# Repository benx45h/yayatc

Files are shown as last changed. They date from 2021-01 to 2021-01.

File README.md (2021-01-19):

# YAYATC- Yet Another YATC
### A new temperature controller, because the YATC links were broken.

YAYATC is a temperature controller designed to heat or cool things to any temperature, within reason. YAYATC can handle either a 10k NTC thermistor or the 1-wire thing from Sparkfun as a temperature sensor. As long as only one is plugged in, YAYATC will automatically detect which to use.
No external power supply is needed- all circuitry is powered directly from the wall.  

The goal here was to minimize design time, and other temperature controllers may have better performance, cheaper BOMs, easier assembly, etc.

Revision 1 has not been tested. If you want to make one anyways, go ahead.

Revision 1 known issues:
~~ - No way to tell if temperature is positive or negative ~~  
~~ - Only 2 digits. No way to display temperatures above 100. ~~

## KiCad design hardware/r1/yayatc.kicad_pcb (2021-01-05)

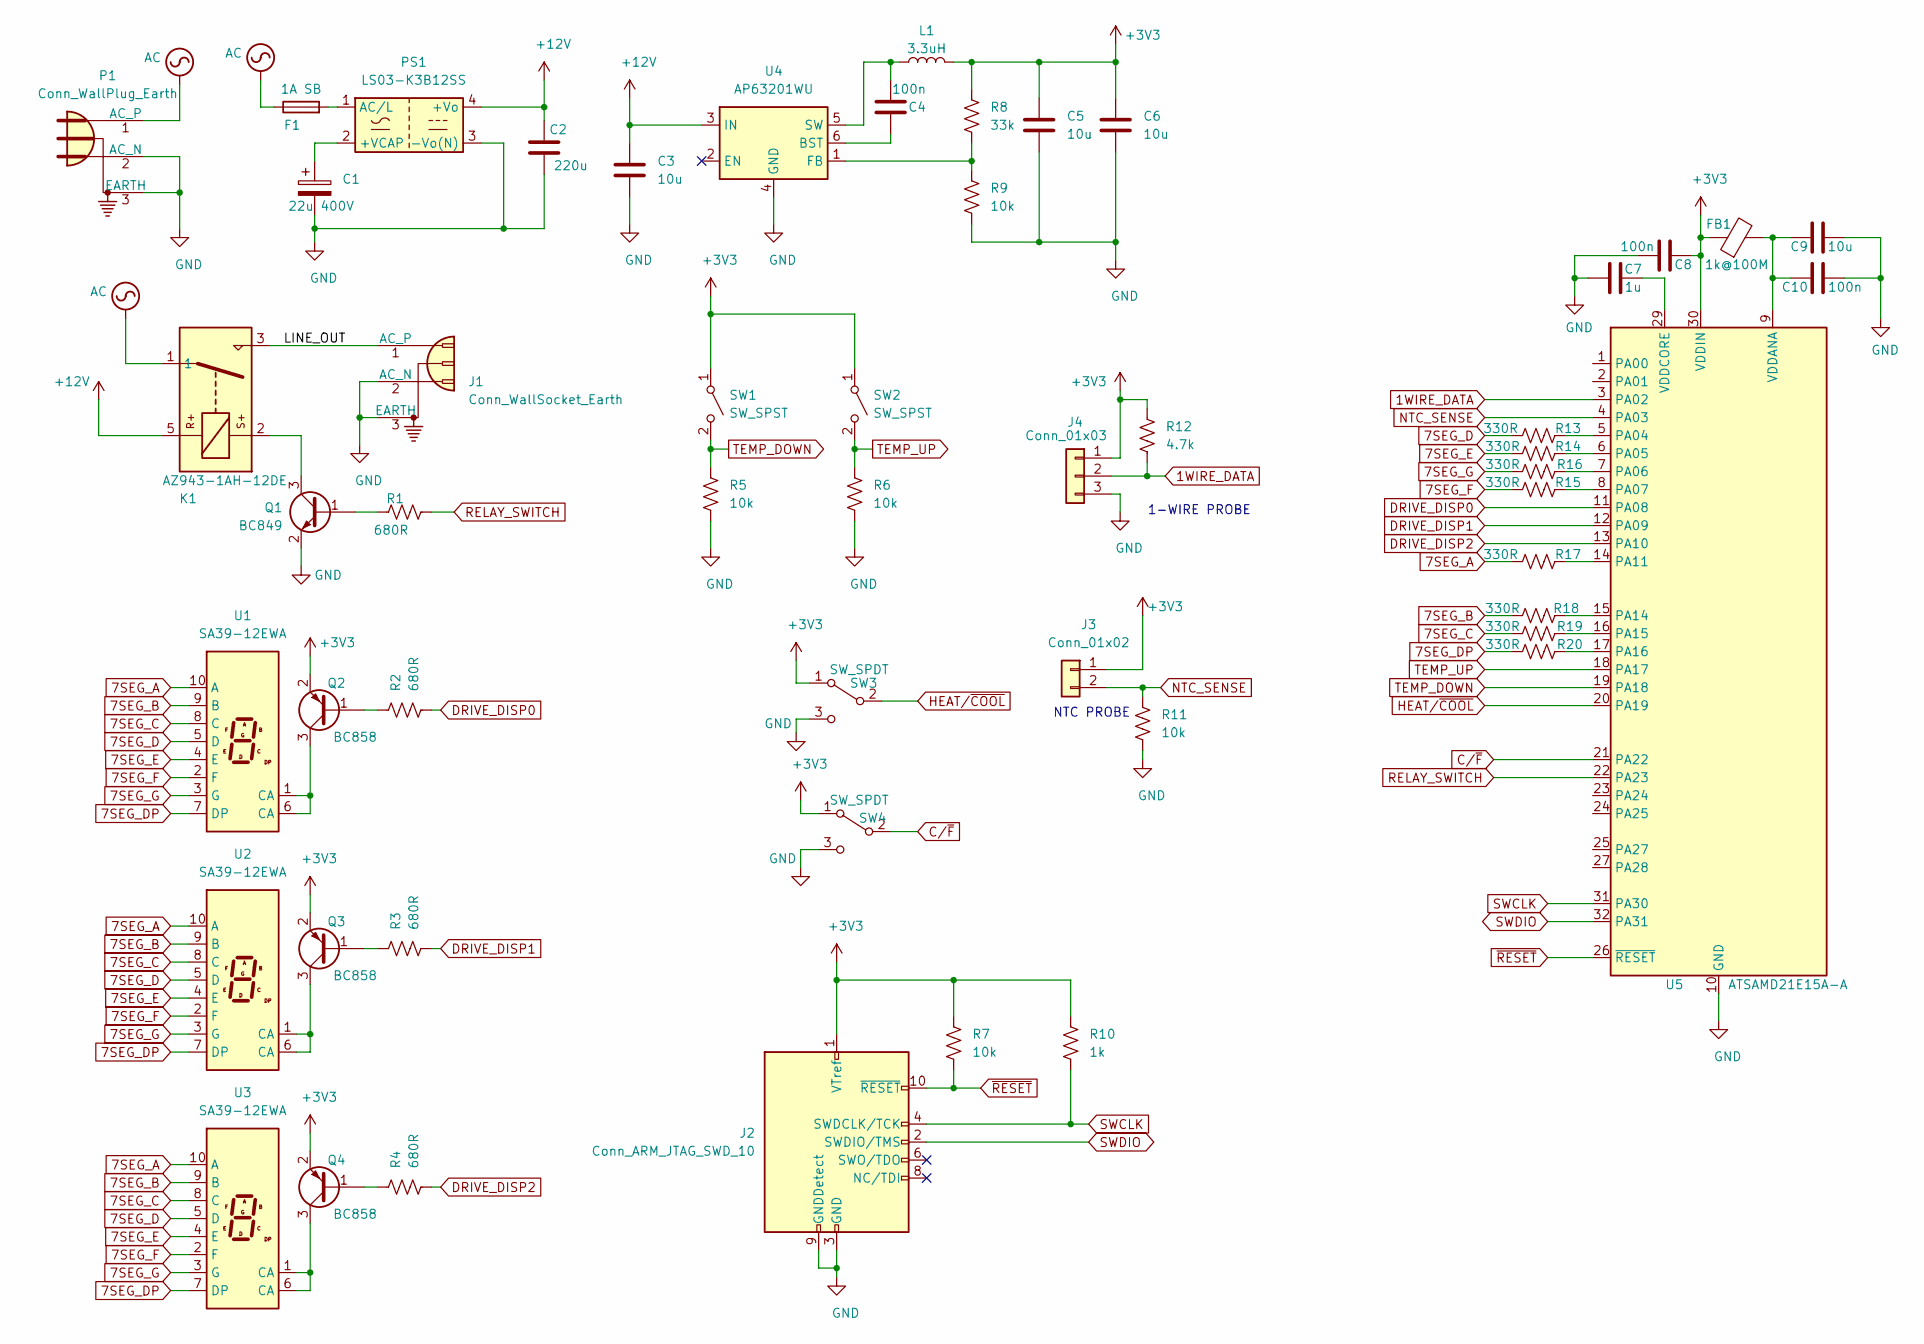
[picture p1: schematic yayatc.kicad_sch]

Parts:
C1: 22u 400V; CP_Radial_D12.5mm_P5.00mm; Digikey-PN 493-5875-ND
C2: 220u; CP_Radial_D6.3mm_P2.50mm; Digikey-PN 732-8797-1-ND
C3, C5, C6, C9: 10u; C_0805_2012Metric_Pad1.18x1.45mm_HandSolder; Digikey-PN 1276-6455-1-ND
C4, C8, C10: 100n; C_0603_1608Metric_Pad1.08x0.95mm_HandSolder; Digikey-PN 1276-CL10B104KB8NNNLCT-ND
C7: 1u; C_0603_1608Metric_Pad1.08x0.95mm_HandSolder; Digikey-PN 1276-1102-1-ND
F1: 1A SB; 0697H1000-02; Digikey-PN 507-1927-1-ND
FB1: 1k@100M; L_0603_1608Metric_Pad1.05x0.95mm_HandSolder; Digikey-PN 587-1895-1-ND
J1: Conn_WallSocket_Earth; SolderWire-1sqmm_1x03_P5.4mm_D1.4mm_OD2.7mm; Digikey-PN Q337-ND
J2: Conn_ARM_JTAG_SWD_10; PinHeader_2x05_P1.27mm_Vertical; Digikey-PN 1849-PR20B05VBDN-ND
J3: Conn_01x02; JST_PH_B2B-PH-K_1x02_P2.00mm_Vertical; Digikey-PN 455-1704-ND
J4: Conn_01x03; JST_PH_B3B-PH-K_1x03_P2.00mm_Vertical; Digikey-PN 455-1704-ND
K1: AZ943-1AH-12DE; Relay_AZ945_A; Digikey-PN 2487-AZ943-1AH-12DE-ND
L1: 3.3uH; L_0805_2012Metric_Pad1.15x1.40mm_HandSolder; Digikey-PN 445-6759-1-ND
P1: Conn_WallPlug_Earth; 703W-00-54; Digikey-PN Q220-ND
PS1: LS03-K3B12SS; LSxx-K3BxxSS; Digikey-PN 2725-LS03-K3B12SS-ND
Q1: BC849; SOT-23; Digikey-PN BC849B-TPMSCT-ND
Q2, Q3, Q4: BC858; SOT-23; Digikey-PN BC858CLT3GOSCT-ND
R1, R2, R3, R4: 680R; R_0603_1608Metric_Pad0.98x0.95mm_HandSolder; Digikey-PN RR08P680DCT-ND
R5, R6, R7, R9, R11: 10k; R_0603_1608Metric_Pad0.98x0.95mm_HandSolder; Digikey-PN RR08P10.0KDCT-ND
R8: 33k; R_0603_1608Metric_Pad0.98x0.95mm_HandSolder; Digikey-PN 311-33.0KHRCT-ND
R10: 1k; R_0603_1608Metric_Pad0.98x0.95mm_HandSolder; Digikey-PN RR08P1.0KDCT-ND
R12: 4.7k; R_0603_1608Metric_Pad0.98x0.95mm_HandSolder; Digikey-PN 311-4.70KHRCT-ND
R13, R14, R15, R16, R17, R18, R19, R20: 330R; R_0603_1608Metric_Pad0.98x0.95mm_HandSolder; Digikey-PN 311-330HRCT-ND
SW1, SW2: SW_SPST; SW_PUSH_6mm_H13mm; Digikey-PN 450-1642-ND
SW3, SW4: SW_SPDT; OS102011MS2Q*; Digikey-PN CKN9565-ND
U1, U2, U3: SA39-12EWA; Sx39-1xxxxx; Digikey-PN 3011-SA39-12EWA-ND
U4: AP63201WU; TSOT-23-6; Digikey-PN 31-AP62301Z6-7CT-ND
U5: ATSAMD21E15A-A; TQFP-32_7x7mm_P0.8mm; Digikey-PN ATSAMD21E17L-AFTCT-ND

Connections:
1WIRE_DATA: J4.2, R12.2, U5.3 (PA02)
7SEG_A: R17.1, U1.10 (A), U2.10 (A), U3.10 (A)
7SEG_B: R18.1, U1.9 (B), U2.9 (B), U3.9 (B)
7SEG_C: R19.1, U1.8 (C), U2.8 (C), U3.8 (C)
7SEG_D: R13.1, U1.5 (D), U2.5 (D), U3.5 (D)
7SEG_DP: R20.1, U1.7 (DP), U2.7 (DP), U3.7 (DP)
7SEG_E: R14.1, U1.4 (E), U2.4 (E), U3.4 (E)
7SEG_F: R15.1, U1.2 (F), U2.2 (F), U3.2 (F)
7SEG_G: R16.1, U1.3 (G), U2.3 (G), U3.3 (G)
+3V3: C5.1, C6.1, C8.1, FB1.1, J2.1 (VTref), J3.1, J4.1, L1.2, Q2.2 (E), Q3.2 (E), Q4.2 (E), R7.1, R8.1, R10.1, R12.1, SW1.1 (A), SW2.1 (A), SW3.1 (A), SW4.1 (A), U5.30 (VDDIN)
+12V: C2.1, C3.1, K1.5, PS1.4 (+Vo), U4.3 (IN)
/LINE_OUT: J1.1 (AC_P), K1.3
AC: F1.1, K1.1, P1.1 (AC_P)
C/~F: SW4.2 (B), U5.21 (PA22)
DRIVE_DISP0: R2.2, U5.11 (PA08)
DRIVE_DISP1: R3.2, U5.12 (PA09)
DRIVE_DISP2: R4.2, U5.13 (PA10)
GND: C1.2, C2.2, C3.2, C5.2, C6.2, C7.1, C8.2, C9.2, C10.2, J1.2 (AC_N), J1.3 (EARTH), J2.3 (GND), J2.5 (GND), J2.9 (GNDDetect), J4.3, P1.2 (AC_N), P1.3 (EARTH), PS1.3 (-Vo(N)), Q1.2 (E), R5.2, R6.2, R9.2, R11.2, SW3.3 (C), SW4.3 (C), U4.4 (GND), U5.10 (GND), U5.28 (GND)
HEAT/~COOL: SW3.2 (B), U5.20 (PA19)
NTC_SENSE: J3.2, R11.1, U5.4 (PA03)
unnamed: C1.1, PS1.2 (+VCAP)
unnamed: C4.1, U4.6 (BST)
unnamed: C4.2, L1.1, U4.5 (SW)
unnamed: C7.2, U5.29 (VDDCORE)
unnamed: C9.1, C10.1, FB1.2, U5.9 (VDDANA)
unnamed: F1.2, PS1.1 (AC/L)
unnamed: K1.2, Q1.3 (C)
unnamed: Q1.1 (B), R1.1
unnamed: Q2.1 (B), R2.1
unnamed: Q2.3 (C), U1.1 (CA), U1.6 (CA)
unnamed: Q3.1 (B), R3.1
unnamed: Q3.3 (C), U2.1 (CA), U2.6 (CA)
unnamed: Q4.1 (B), R4.1
unnamed: Q4.3 (C), U3.1 (CA), U3.6 (CA)
unnamed: R8.2, R9.1, U4.1 (FB)
unnamed: R13.2, U5.5 (PA04)
unnamed: R14.2, U5.6 (PA05)
unnamed: R15.2, U5.8 (PA07)
unnamed: R16.2, U5.7 (PA06)
unnamed: R17.2, U5.14 (PA11)
unnamed: R18.2, U5.15 (PA14)
unnamed: R19.2, U5.16 (PA15)
unnamed: R20.2, U5.17 (PA16)
RELAY_SWITCH: R1.2, U5.22 (PA23)
SWCLK: J2.4 (SWDCLK/TCK), R10.2, U5.31 (PA30)
SWDIO: J2.2 (SWDIO/TMS), U5.32 (PA31)
TEMP_DOWN: R5.1, SW1.2 (B), U5.19 (PA18)
TEMP_UP: R6.1, SW2.2 (B), U5.18 (PA17)
no_connect_56: J2.6 (SWO/TDO)
no_connect_57: J2.8 (NC/TDI)
no_connect_58: U4.2 (EN)
~RESET: J2.10 (~RESET~), R7.2, U5.26 (~RESET)

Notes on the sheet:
NTC PROBE
1-WIRE PROBE

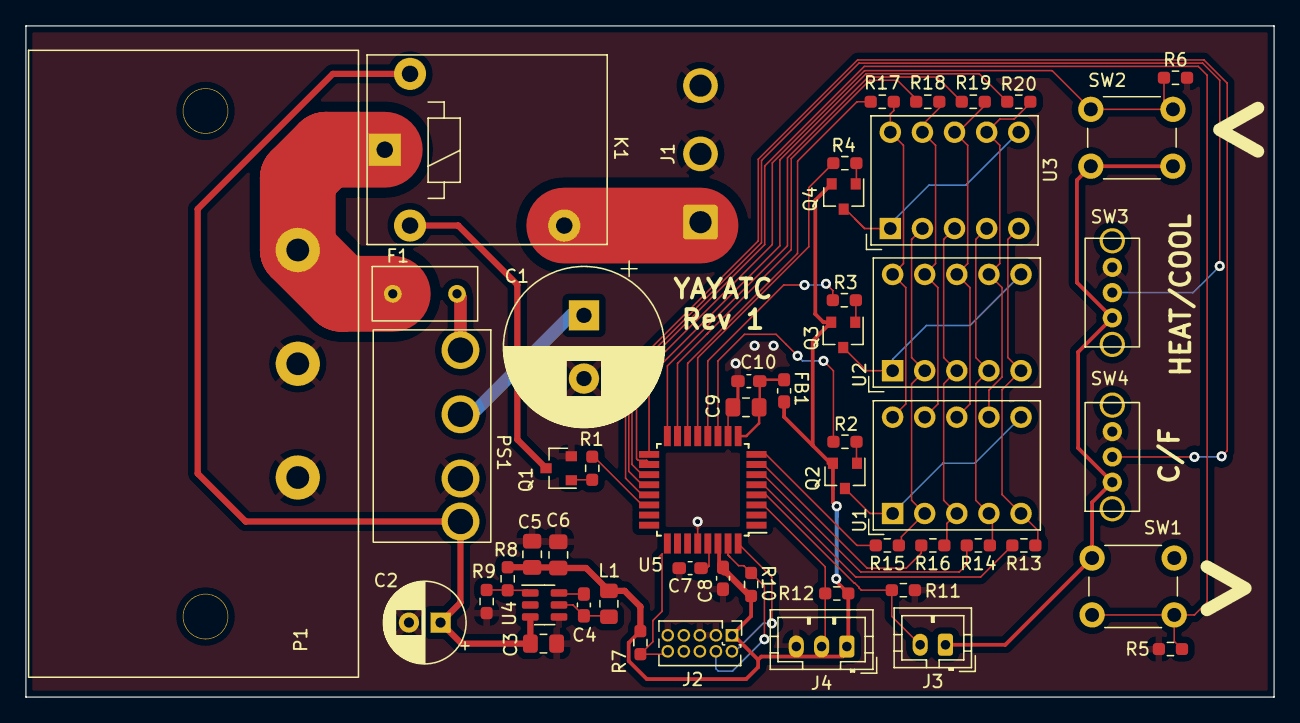
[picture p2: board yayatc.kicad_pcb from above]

Board: 2 copper layers, 98.8 x 53.1 mm, 53 parts (0 on the bottom side), 49 nets.
